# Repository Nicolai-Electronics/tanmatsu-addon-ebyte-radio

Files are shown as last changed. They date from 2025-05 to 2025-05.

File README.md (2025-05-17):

# Tanmatsu add-on: Ebyte radio modules

This repository contains the hardware design files for the Ebyte radio modules addon for the internal add-on connector of Tanmatsu.

## Documentation

Need the schematic? [It's in this repository as a PDF file](schematic.pdf).

## License

This hardware design may be used under the terms of the [CERN-OHL-P](LICENSE) license.

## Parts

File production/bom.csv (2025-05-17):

Designator | Footprint | Quantity | Value | LCSC Part #
C10, C3, C4, C5, C7, C8 | 0402 | 6 | 100n | C307331
C2, C6, C9 | 0805 | 3 | 22u | C602037
J1 | PinHeader_2x18_P2.54mm_Vertical_SMD | 1 | Mainboard | C6332243
J2 | PinHeader_2x05_P2.54mm_Vertical | 1 | Antenna switcher | -
J3 | 1X04_1MM_RA_GND | 1 | I2C | C7433425
J4 | 1X04_1MM_RA_GND | 1 | I3C | C7433425
R1, R2, R4, R5, R6, R7, R8, R9 | 0402 | 8 | 100k | C25741
R10 | 0402 | 1 | 1k | C11702
U1 | WIRELM-SMD_E22-900M22S | 1 | Module 1 | C2965513
U3 | SOP-8_3.9x4.9mm_P1.27mm | 1 | 24C02BN | C18723542
U4 | WIRELM-SMD_E22-900M22S | 1 | Module 2 | C411291
U5, U7 | SOT-353_SC-70-5 | 2 | 74LVC1GU04 | C485082
U6 | WIRELM-SMD_E22-900M22S | 1 | Module 3 | -

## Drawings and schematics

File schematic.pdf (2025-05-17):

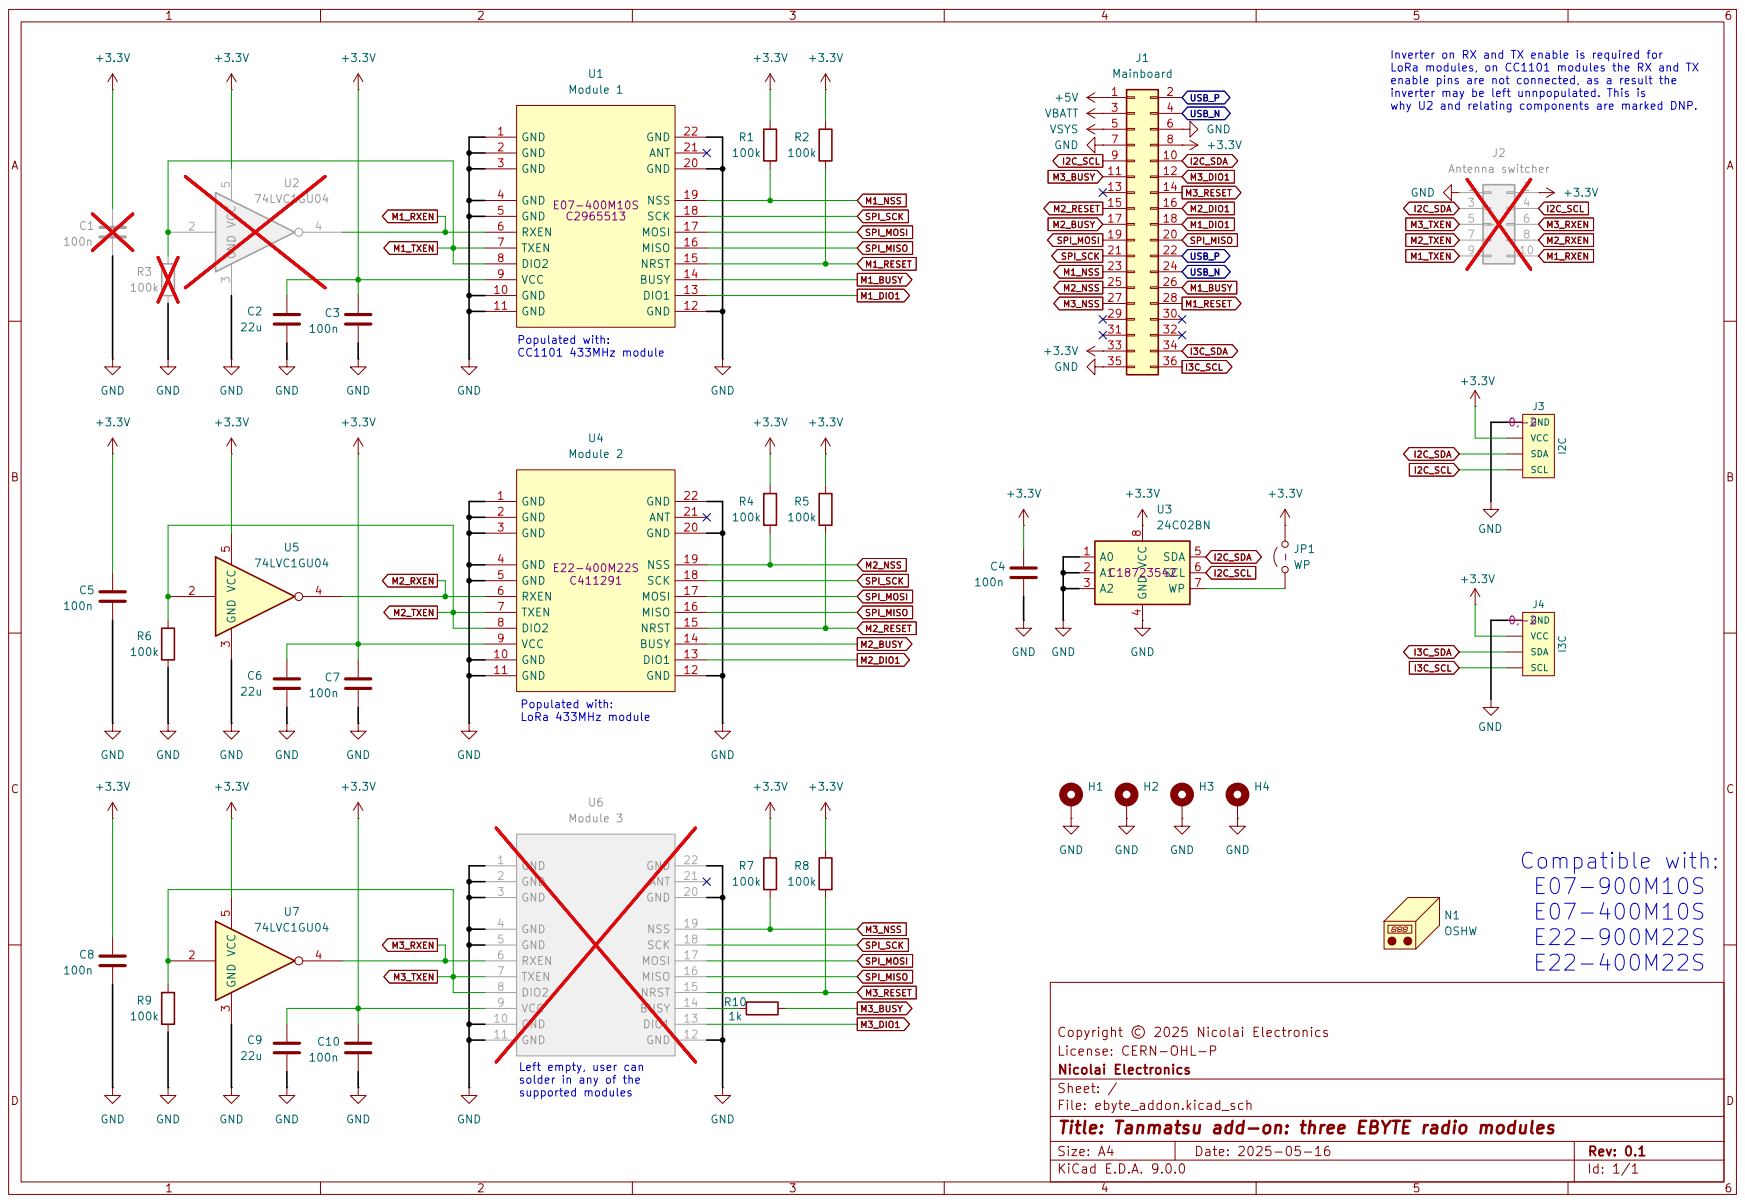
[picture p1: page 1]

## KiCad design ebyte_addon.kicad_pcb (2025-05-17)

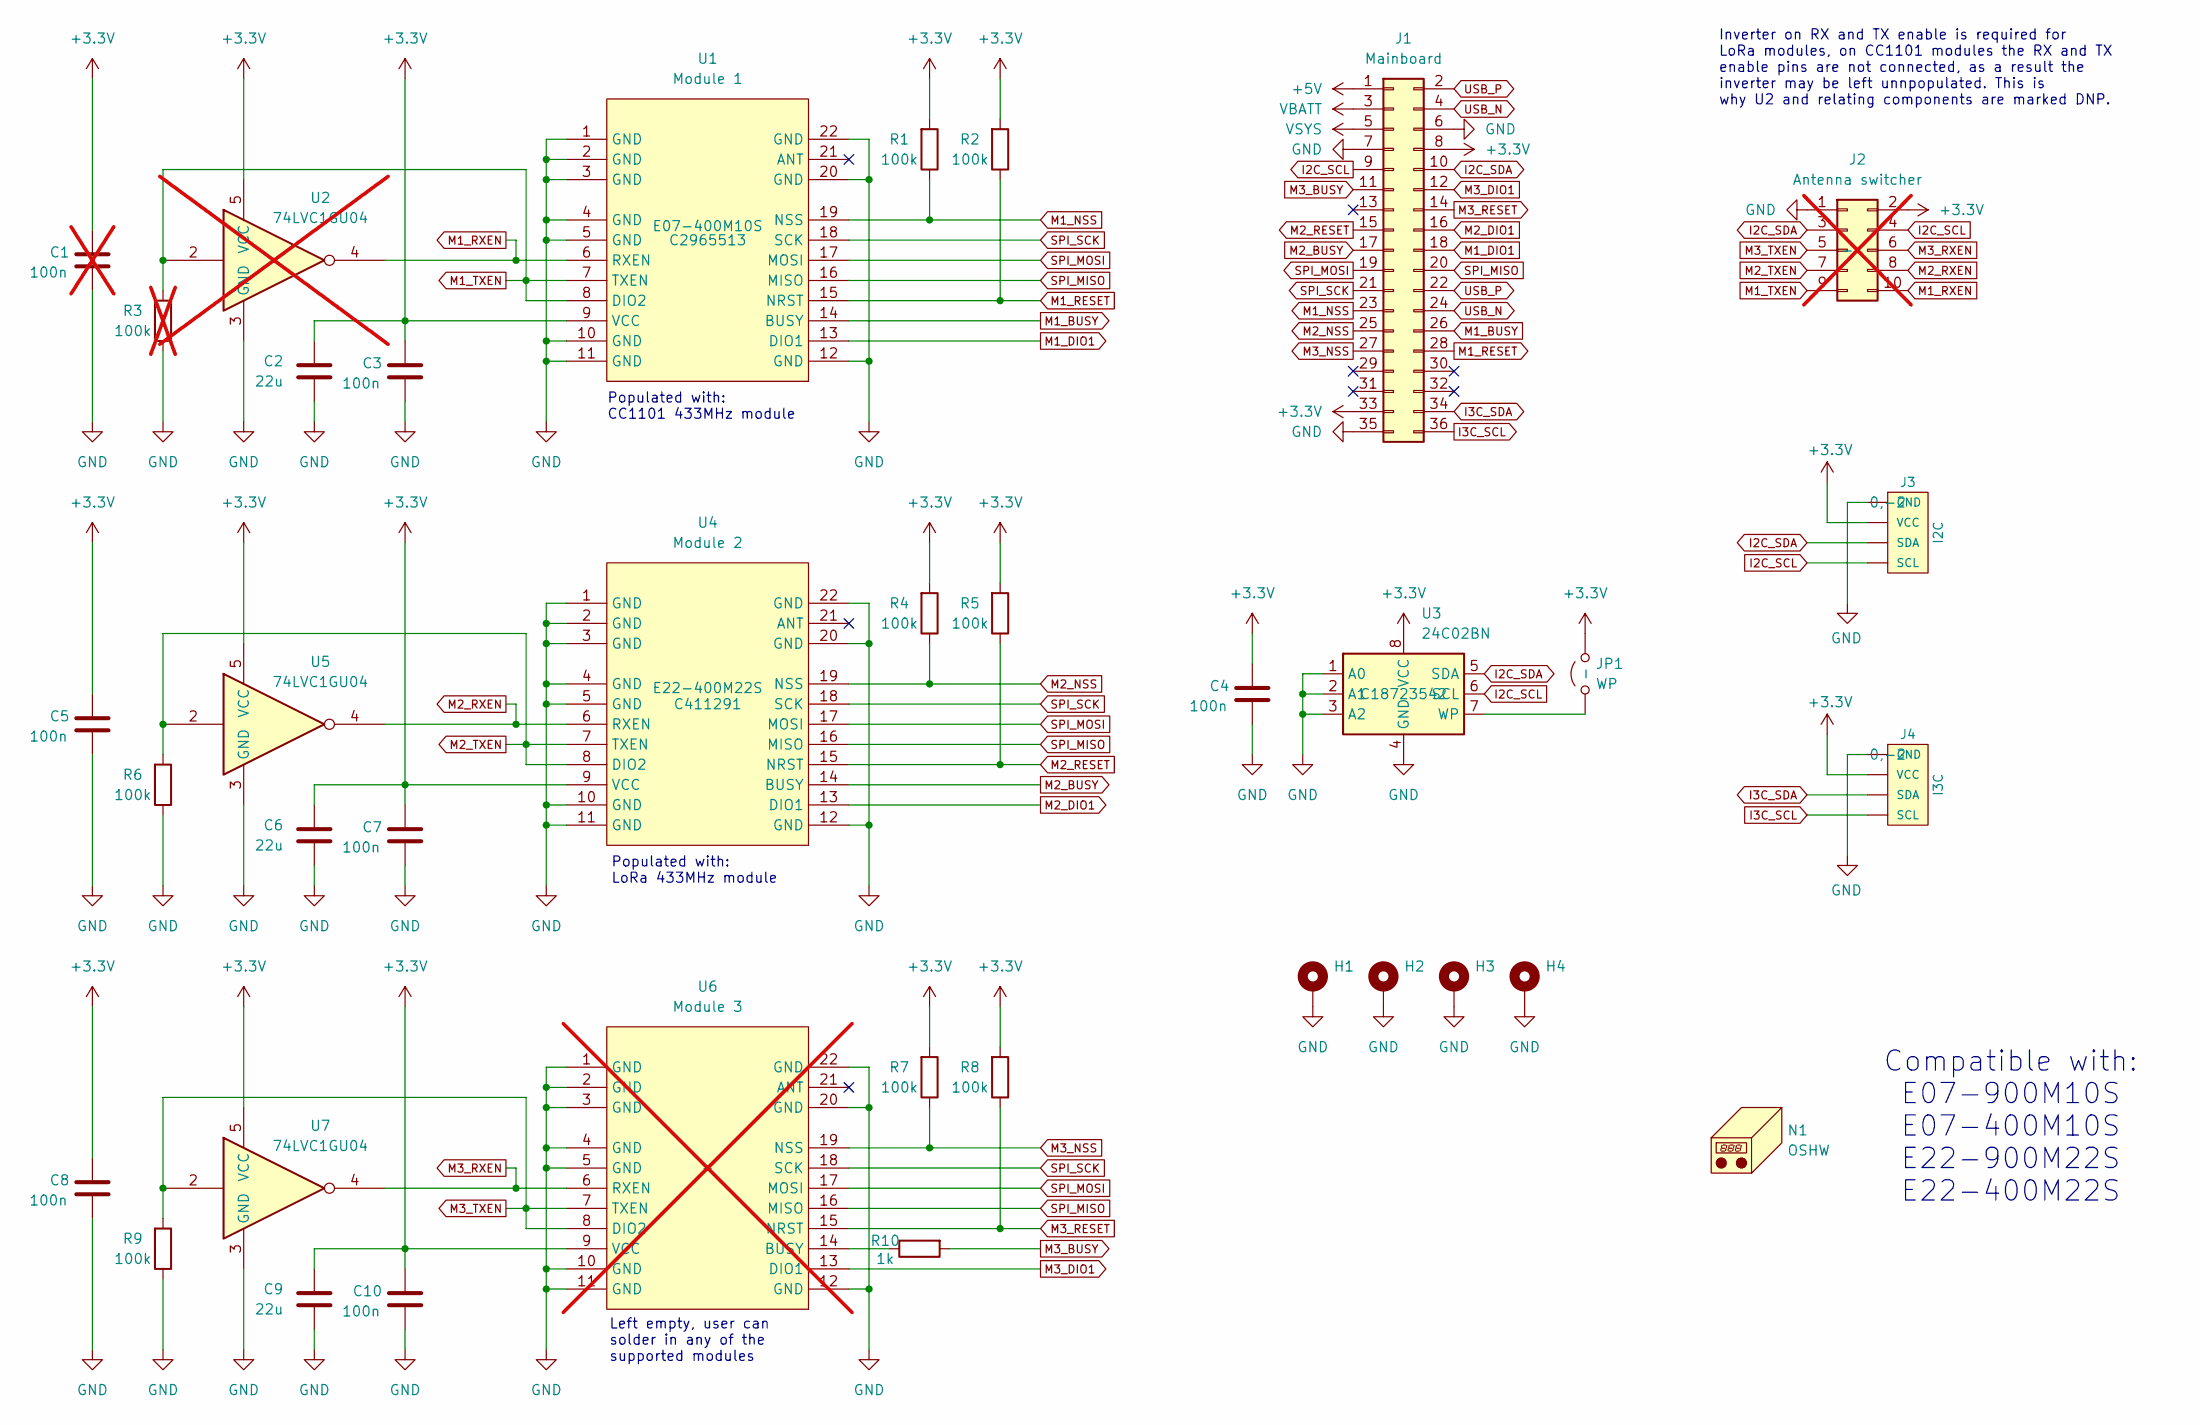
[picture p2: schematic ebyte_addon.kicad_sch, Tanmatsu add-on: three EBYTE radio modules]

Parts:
C1: 100n; C_0402_1005Metric; LCSC C307331; not fitted
C2, C6, C9: 22u; C_0805_2012Metric; LCSC C602037
C3, C4, C5, C7, C8, C10: 100n; C_0402_1005Metric; LCSC C307331
H1, H2, H3, H4: MountingHole_2.2mm_M2_Pad_Via
J1: Mainboard; PinHeader_2x18_P2.54mm_Vertical_SMD; LCSC C6332243
J2: Antenna switcher; PinHeader_2x05_P2.54mm_Vertical; not fitted
J3: I2C; 1X04_1MM_RA_GND; LCSC C7433425
J4: I3C; 1X04_1MM_RA_GND; LCSC C7433425
JP1: WP; SolderJumper-2_P1.3mm_Open_TrianglePad1.0x1.5mm
N1: OSHW; OSHW-Logo2_9.8x8mm_SilkScreen
R1, R2, R4, R5, R6, R7, R8, R9: 100k; R_0402_1005Metric; LCSC C25741
R3: 100k; R_0402_1005Metric; LCSC C25741; not fitted
R10: 1k; R_0402_1005Metric; LCSC C11702
U1: Module 1; WIRELM-SMD_E22-900M22S; LCSC C2965513
U2: 74LVC1GU04; SOT-353_SC-70-5; LCSC C485082; not fitted
U3: 24C02BN; SOP-8_3.9x4.9mm_P1.27mm; LCSC C18723542
U4: Module 2; WIRELM-SMD_E22-900M22S; LCSC C411291
U5, U7: 74LVC1GU04; SOT-353_SC-70-5; LCSC C485082
U6: Module 3; WIRELM-SMD_E22-900M22S; not fitted

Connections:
+3.3V: C1.1, C2.1, C3.1, C4.1, C5.1, C6.1, C7.1, C8.1, C9.1, C10.1, J1.8, J1.33, J2.2, J3.2 (VCC), J4.2 (VCC), JP1.2 (B), R1.2, R2.2, R4.2, R5.2, R7.2, R8.2, U1.9 (VCC), U2.5 (VCC), U3.8 (VCC), U4.9 (VCC), U5.5 (VCC), U6.9 (VCC), U7.5 (VCC)
+5V: J1.1
GND: C1.2, C2.2, C3.2, C4.2, C5.2, C6.2, C7.2, C8.2, C9.2, C10.2, H1.1, H2.1, H3.1, H4.1, J1.6, J1.7, J1.35, J2.1, J3.1 (GND), J3.5, J3.6, J4.1 (GND), J4.5, J4.6, R3.1, R6.1, R9.1, U1.1 (GND), U1.2 (GND), U1.3 (GND), U1.4 (GND), U1.5 (GND), U1.10 (GND), U1.11 (GND), U1.12 (GND), U1.20 (GND), U1.22 (GND), U2.3 (GND), U3.1 (A0), U3.2 (A1), U3.3 (A2), U3.4 (GND), U4.1 (GND), U4.2 (GND), U4.3 (GND), U4.4 (GND), U4.5 (GND), U4.10 (GND), U4.11 (GND), U4.12 (GND), U4.20 (GND), U4.22 (GND), U5.3 (GND), U6.1 (GND), U6.2 (GND), U6.3 (GND), U6.4 (GND), U6.5 (GND), U6.10 (GND), U6.11 (GND), U6.12 (GND), U6.20 (GND), U6.22 (GND), U7.3 (GND)
I2C_SCL: J1.9, J2.4, J3.4 (SCL), U3.6 (SCL)
I2C_SDA: J1.10, J2.3, J3.3 (SDA), U3.5 (SDA)
I3C_SCL: J1.36, J4.4 (SCL)
I3C_SDA: J1.34, J4.3 (SDA)
M1_BUSY: J1.26, U1.14 (BUSY)
M1_DIO1: J1.18, U1.13 (DIO1)
M1_NSS: J1.23, R1.1, U1.19 (NSS)
M1_RESET: J1.28, R2.1, U1.15 (NRST)
M1_RXEN: J2.10, U1.6 (RXEN), U2.4
M1_TXEN: J2.9, R3.2, U1.7 (TXEN), U1.8 (DIO2), U2.2
M2_BUSY: J1.17, U4.14 (BUSY)
M2_DIO1: J1.16, U4.13 (DIO1)
M2_NSS: J1.25, R4.1, U4.19 (NSS)
M2_RESET: J1.15, R5.1, U4.15 (NRST)
M2_RXEN: J2.8, U4.6 (RXEN), U5.4
M2_TXEN: J2.7, R6.2, U4.7 (TXEN), U4.8 (DIO2), U5.2
M3_BUSY: J1.11, R10.2
M3_DIO1: J1.12, U6.13 (DIO1)
M3_NSS: J1.27, R7.1, U6.19 (NSS)
M3_RESET: J1.14, R8.1, U6.15 (NRST)
M3_RXEN: J2.6, U6.6 (RXEN), U7.4
M3_TXEN: J2.5, R9.2, U6.7 (TXEN), U6.8 (DIO2), U7.2
unnamed: JP1.1 (A), U3.7 (WP)
unnamed: R10.1, U6.14 (BUSY)
SPI_MISO: J1.20, U1.16 (MISO), U4.16 (MISO), U6.16 (MISO)
SPI_MOSI: J1.19, U1.17 (MOSI), U4.17 (MOSI), U6.17 (MOSI)
SPI_SCK: J1.21, U1.18 (SCK), U4.18 (SCK), U6.18 (SCK)
USB_N: J1.4, J1.24
USB_P: J1.2, J1.22
VBATT: J1.3
VSYS: J1.5

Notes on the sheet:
Inverter on RX and TX enable is required for LoRa modules, on CC1101 modules the RX and TX enable pins are not connected, as a result the inverter may be left unnpopulated. This is why U2 and relating components are marked DNP.
Compatible with: E07-900M10S E07-400M10S E22-900M22S E22-400M22S
Left empty, user can solder in any of the supported modules
Populated with: LoRa 433MHz module
Populated with: CC1101 433MHz module

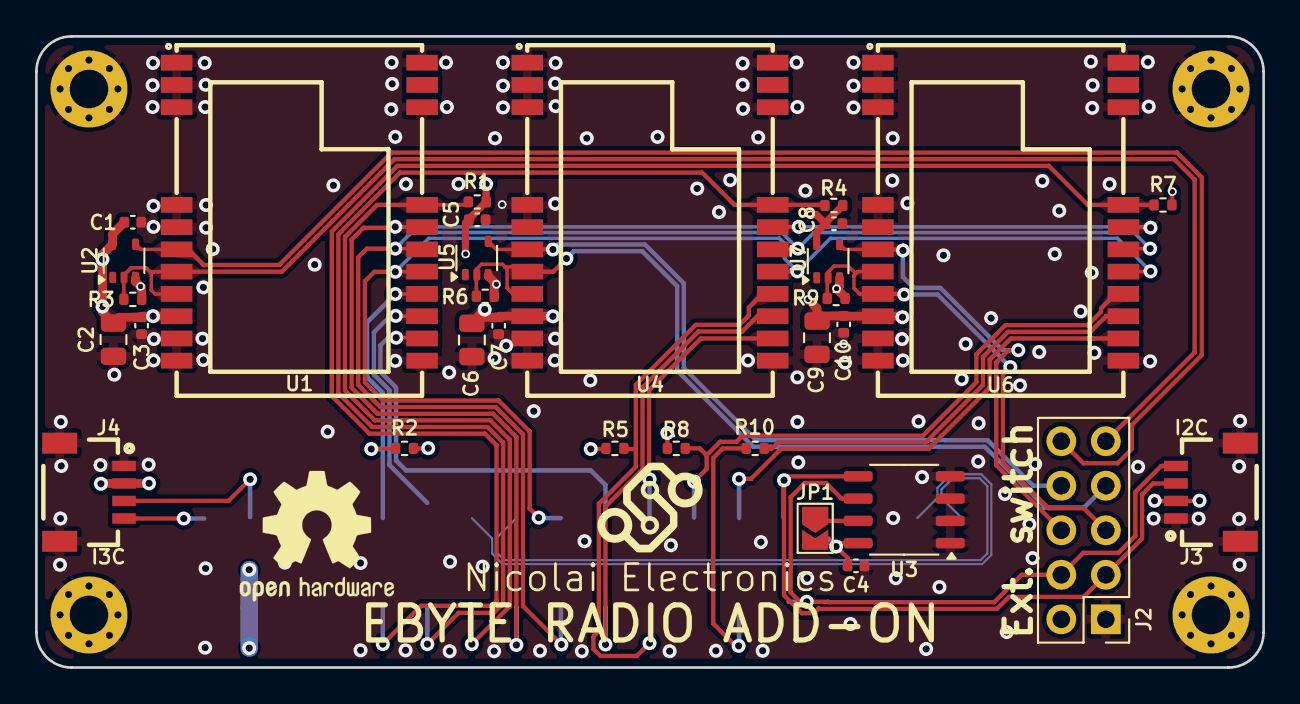
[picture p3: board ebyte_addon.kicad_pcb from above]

Board: 4 copper layers, 70.0 x 36.0 mm, 37 parts (1 on the bottom side), 31 nets.

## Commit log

2025-05-16 Fix connector orientation
    [dual_radio_addon.kicad_pcb, dual_radio_addon.kicad_sch]
2025-05-16 Configure first two radio modules to be populated by manufacturer
    [dual_radio_addon.kicad_pcb, dual_radio_addon.kicad_sch]
2025-05-17 Rename files, add schematic and add notes to schematic
    [bom.csv, designators.csv, ebyte_addon.kicad_pcb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]

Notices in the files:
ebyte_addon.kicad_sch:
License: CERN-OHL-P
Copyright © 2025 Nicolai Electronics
